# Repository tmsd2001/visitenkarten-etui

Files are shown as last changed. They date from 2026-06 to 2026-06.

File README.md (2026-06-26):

# 🛡️ Bulletproof Visitenkarten-Etui (OpenSCAD)

Ein extrem robustes, zweiteiliges Visitenkarten-Etui im "Matroschka"-Stil für den harten Alltag in der Hosentasche (EDC). Entworfen in OpenSCAD, optimiert für den Support-freien FDM-Druck. Das Etui besteht aus einem Innenteil (Schieber) und einer passgenauen Außenhülle mit integriertem Klick-Verschluss. 

Zusätzlich enthält dieses Projekt eine parametrische, zweifarbige Deckkarte (3D-gedruckte Visitenkarte) in massiver Ausführung, die als Schutz für die eigentlichen Papierkarten dient.

## 📐 Features
* **Zweiteiliges Schiebe-Design:** Innenteil und Außenhülle gleiten durch berechnete Toleranzen passgenau ineinander.
* **Integrierte Rastung:** Kleine gedruckte Halbkugeln sorgen für ein sattes "Klicken" beim Schließen – das Etui geht in der Tasche nicht von alleine auf.
* **Support-Free:** Durch clevere Konstruktion und aufrechtes Drucken auf der Rückwand komplett ohne Stützstrukturen druckbar.
* **Hosentaschen-optimiert:** Abgerundete Kanten (3 mm Radius) verhindern unangenehmes Drücken.
* **Ergonomisch:** Die vordere Daumen-Mulde erlaubt das einfache Herausschieben der Karten.
* **Parametrisch:** Vollständig anpassbar in OpenSCAD (inklusive einstellbarer Gleit-Toleranz).

## 🛠️ Druck-Parameter (Cura Slicer / Anycubic i3 Mega)
* **Ausrichtung:** Beide Gehäuseteile **zwingend um 90 Grad auf die geschlossene Rückwand stellen** (hoher Turm), um Support-Strukturen im Innenraum zu vermeiden!
* **Schichthöhe:** 0.16 mm 
* **Wandlinien:** 6 (für maximale Stabilität)
* **Infill:** 20 % Gyroid
* **Temperaturen:** 210 °C Hotend / 60 °C Ultrabase
* **Kühlung:** 100 % (Start ab Schicht 3)
* **Z-Hop:** Deaktiviert
* **Haftung:** Skirt (bei Haftungsproblemen der hohen Bauteile auf Brim wechseln)

💡 **Tipp für den perfekten Lauf:** Da die Layer-Linien beider Bauteile parallel verlaufen, kann es beim ersten Einschieben zum "Zipper-Effekt" kommen. Ziehe die Außenseiten des Innenteils einfach 3-4 Mal über ein Stück feines Schleifpapier. So brechen die mikroskopischen Layer-Spitzen, und das Etui gleitet völlig butterweich.

## 🎨 Anleitung: Die zweifarbige Deckkarte (Massiv-Version)
Die aktualisierte Deckkarte mit optimierter, vergrößerter Schrift ist exakt auf 0.16 mm Schichthöhe programmiert. Nutze **nicht** das Cura-Plugin "Pause at Height", sondern pausiere manuell über das Drucker-Display, sobald der massive Grundkörper fertig ist, um das Filament für die erhabene Schrift zu wechseln!

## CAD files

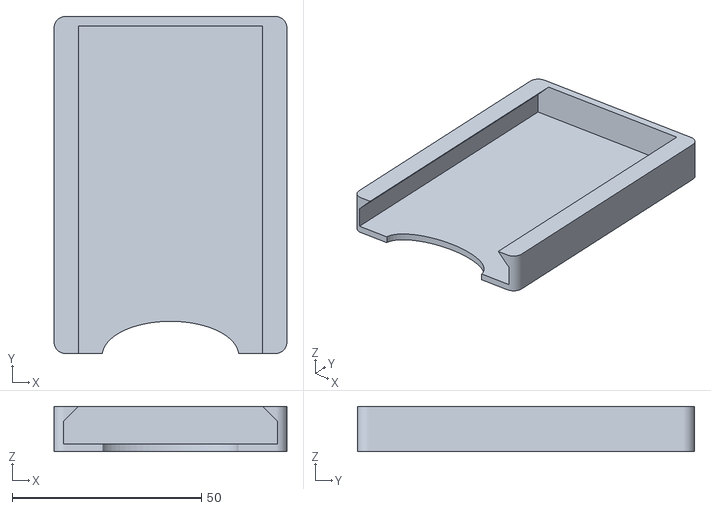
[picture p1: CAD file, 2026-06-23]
stl/etui.stl
61.5 x 89.0 x 12.0

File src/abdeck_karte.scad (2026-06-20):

// 3D-gedruckte Visitenkarte / Deckkarte für das Etui
// 100% optimiert für Schichthöhe 0.16mm und manuellen Filamentwechsel

/* [Karten-Maße] */
karte_l = 85;
karte_b = 55;
r_ecken = 1.5;

/* [Dicken exakt nach Schichten] */
basis_h = 0.64;
relief_h = 0.48;

/* [Inhalt] */
vorname = "MAX";
nachname = "MUSTERMANN";
titel = "BEZEICHNUNG";

module basis_karte() {
    hull() {
        translate([r_ecken, r_ecken, 0]) cylinder(h=basis_h, r=r_ecken, $fn=60);
        translate([karte_l-r_ecken, r_ecken, 0]) cylinder(h=basis_h, r=r_ecken, $fn=60);
        translate([karte_l-r_ecken, karte_b-r_ecken, 0]) cylinder(h=basis_h, r=r_ecken, $fn=60);
        translate([r_ecken, karte_b-r_ecken, 0]) cylinder(h=basis_h, r=r_ecken, $fn=60);
    }
}

module text_relief() {
    translate([8, 34, basis_h])
        linear_extrude(height=relief_h)
            text(vorname, size=4.5, font="Roboto:style=Bold", spacing=1.1);
            
    translate([8, 22, basis_h])
        linear_extrude(height=relief_h)
            text(nachname, size=7, font="Roboto:style=Black", spacing=1.1);

    translate([8, 17, basis_h])
        cube([karte_l - 16, 0.8, relief_h]);

    translate([8, 11, basis_h])
        linear_extrude(height=relief_h)
            text(titel, size=3.2, font="Roboto:style=Regular", spacing=1.05);
}

translate([-karte_l/2, -karte_b/2, 0]) {
    basis_karte();
    text_relief();
}

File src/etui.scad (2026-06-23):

//
// Parameters
//

// Card dimensions
card_width            = 55;
card_length           = 85;
card_stack_height     = 6;

// Manufacturing tolerances
clearance             = 1.5;

// Case geometry
wall_thickness        = 2.5;
bottom_thickness      = 2.0;
outer_corner_radius   = 3.0;

// Retention lip
retention_lip_size    = 4.0;

// Thumb cutout
thumb_cutout_radius   = 18;
thumb_cutout_y_offset = -0.5;
thumb_cutout_scale_y  = 0.5;

// Rendering
render_resolution     = 60;
$fn = render_resolution;


//
// Derived dimensions
//
inner_width  = card_width + clearance;
inner_length = card_length + clearance;

// Open-front design:
// rear wall only, front side remains open
outer_width  = inner_width + 2 * wall_thickness;
outer_length = inner_length + wall_thickness;

outer_height =
    bottom_thickness +
    card_stack_height +
    retention_lip_size;


//
// Rounded block
//
module rounded_block(
    width,
    length,
    height,
    corner_radius
) {

    hull() {

        for (x = [0, 1])
        for (y = [0, 1]) {

            translate([
                x * (width  - 2 * corner_radius) + corner_radius,
                y * (length - 2 * corner_radius) + corner_radius,
                0
            ])

            cylinder(
                h = height,
                r = corner_radius
            );
        }
    }
}


//
// Main card holder
//
module card_holder() {

    difference() {

        //
        // Outer body
        //
        rounded_block(
            outer_width,
            outer_length,
            outer_height,
            outer_corner_radius
        );

        //
        // Card compartment
        //
        translate([
            wall_thickness,
            -1,
            bottom_thickness
        ])

        cube([
            inner_width,
            inner_length + 1,
            card_stack_height
        ]);

        //
        // 45° support-free roof transition
        //
        translate([
            wall_thickness,
            -1,
            bottom_thickness + card_stack_height
        ])

        hull() {

            cube([
                inner_width,
                inner_length + 1,
                0.01
            ]);

            translate([
                retention_lip_size,
                0,
                retention_lip_size
            ])

            cube([
                inner_width - 2 * retention_lip_size,
                inner_length + 1,
                0.01
            ]);
        }

        //
        // Thumb access cutout
        //
        translate([
            outer_width / 2,
            thumb_cutout_y_offset,
            bottom_thickness + card_stack_height / 2
        ])

        scale([
            1,
            thumb_cutout_scale_y,
            1
        ])

        cylinder(
            h      = outer_height + 5,
            r      = thumb_cutout_radius,
            center = true
        );
    }
}


//
// Final assembly
//
translate([
    -outer_width / 2,
    -outer_length / 2,
    0
]) {

    card_holder();
}

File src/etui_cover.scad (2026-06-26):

$fn = 60;

//
// Parameters
//

// Base dimension parameters (Inner card stack)
card_width = 56.5;
card_length = 86.5;
stack_height = 6.0;

// Shell structural parameters
wall_thickness = 2.5;
bottom_thickness = 2.0;
outer_radius = 3.0;
lip_height = 4.0;

// Fitment and tolerances
sliding_tolerance = 0.25;      // Clearance for a smooth sliding fit
snap_radius = 0.9;             // Radius of the snap-fit indents
snap_y_offset = 15.0;          // Y-axis distance from the back for snap-fit spheres
thumb_cutout_radius = 18.0;    // Radius for the thumb access cutout

// Calculated base part dimensions
base_x = card_width + 2 * wall_thickness;
base_y = card_length + wall_thickness;
base_z = bottom_thickness + stack_height + lip_height;

// Calculated inner shell dimensions (base + tolerance)
inner_x = base_x + 2 * sliding_tolerance;
inner_y = base_y + sliding_tolerance;
inner_z = base_z + sliding_tolerance;

// Calculated total outer shell dimensions
total_x = inner_x + 2 * wall_thickness;
total_y = inner_y + wall_thickness;
total_z = bottom_thickness + inner_z + lip_height;

//
// Helper modules
//

// Generates a rectangular solid with rounded corners in the XY plane
module rounded_cuboid(x_size, y_size, z_size, radius) {
    hull() {
        for (i = [0, 1]) {
            for (j = [0, 1]) {
                translate([
                    i * (x_size - 2 * radius) + radius, 
                    j * (y_size - 2 * radius) + radius, 
                    0
                ]) 
                cylinder(h = z_size, r = radius);
            }
        }
    }
}

//
// Main geometry
//

module outer_shell() {
    difference() {
        // 1. Main outer body
        rounded_cuboid(total_x, total_y, total_z, outer_radius);
        
        // 2. Inner void for the bottom part
        translate([wall_thickness, -1, bottom_thickness])
            cube([inner_x, inner_y + 1, inner_z]);
            
        // 3. Internal 45-degree chamfer for support-free roof printing
        translate([wall_thickness, -1, bottom_thickness + inner_z])
            hull() {
                cube([inner_x, inner_y + 1, 0.01]);
                translate([lip_height, 0, lip_height])
                    cube([inner_x - 2 * lip_height, inner_y + 1, 0.01]);
            }
            
        // 4. Elliptical thumb access cutout
        translate([total_x / 2, -0.5, bottom_thickness + inner_z / 2])
            scale([1, 0.5, 1]) 
            cylinder(h = total_z + 5, r = thumb_cutout_radius, center = true);
            
        // 5. Integrated snap-fit recesses (negatives for bottom part detents)
        for (x_pos = [wall_thickness, total_x - wall_thickness]) {
            translate([x_pos, inner_y - snap_y_offset, bottom_thickness + inner_z / 2]) 
                sphere(r = snap_radius, $fn = 30);
        }
    }
}

//
// Final assembly
//

// Center the part on the build plate for standard FDM printing
translate([-total_x / 2, -total_y / 2, 0])
    outer_shell();

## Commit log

2026-06-20 Initial commit: Projektstruktur, OpenSCAD-Code und README erstellt
    [abdeck_karte.scad, etui.scad]
2026-06-20 feat: optimize etui geometry and refactor OpenSCAD code
    [etui.scad]
2026-06-23 refactor: standardize business card holder model structure
    Translate identifiers and comments to English
    Organize parameters into logical groups
    Improve code readability and maintainability
    Add explicit derived dimension section
    Standardize module structure and formatting
    Prepare model for future parameterization
    [etui.scad]
2026-06-23 refactor: fully parameterize business card holder model
    Add configurable thumb cutout parameters
    Standardize rendering configuration
    Rename retention lip parameter for clarity
    Document open-front enclosure design
    Improve maintainability and readability
    [etui.scad]
2026-06-23 feat: add initial business card holder STL model
    [etui.stl]
2026-06-26 refactor: modernize outer shell code structure and translate to English
    [etui_cover.scad]
2026-06-26 docs: README für das neue zweiteilige Etui aktualisiert
    Beschreibung auf das neue zweiteilige "Matroschka"-Design geändert
    Neue Features dokumentiert (Klick-Rastung, Schiebe-Design)
    Wichtige Druck-Parameter (90-Grad-Ausrichtung) und Schleifpapier-Tipp hinzugefügt
    Anleitung für die massivere Version der Deckkarte angepasst
